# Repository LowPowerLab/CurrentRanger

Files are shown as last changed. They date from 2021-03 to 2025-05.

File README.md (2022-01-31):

# CurrentRanger
Precision auto-ranging current meter (ammeter)

## [Please see the full guide and latest updates posted here.](https://lowpowerlab.com/guide/currentranger/)



## Quick Highlights
Here are some of the features of this instrument which sets it apart:

* Low noise zero-offset with 3-ranges (1mV output per nA/µA/mA)
* Low input burden voltage, high precision & bandwidth analog outputs
* Increased flexibility and usability with several input and output terminal options
* Fast auto-ranging capable
* Use standalone with a small OLED display or with a multimeter/oscilloscope
* Ultra fast range switching between any ranges (even nA to mA) without any glitching/bouncing of a mechanical switch
* Low Pass Filter mode – very useful to capture low noise  signals on oscilloscopes
* Unidirectional mode – most used mode in measuring DC currents ranging from [0, 3.3A]
* Bidirectional mode – split supply biasing allows AC currents measurement ranging from [-1.65A, 1.65A]
* LiPo battery powered – long life and extended measurement range
* Auto-power-off
* Full digital control for power & range switching via touch pads
* OLED display option to read output with usable precision
* Datalogging possible via Bluetooth serial module or USB (use USB isolator, [see guide](https://lowpowerlab.com/guide/currentranger/safety-and-proper-usage/))
* SAMD21 Cortex M0+ powered, change firmware to your needs
* Optional buzzer for audible feedback

* Current ranges output:
  - 0-3300 nA/µA/mA (Unidirectional mode)
  - +/- 0-1650 nA/µA/mA (Bidirectional mode)
  - Burden voltage:
  - 17µV/mA
  - 10µV/µA
  - 10µV/nA
* Output offset voltage¹: typically <10µV, max 50µV
* Maximum input voltage differential (see Safety): 33mV
* Accuracy:
  - +/-0.05% (µA, nA ranges)
  - +/-0.1% (mA range)
* Highest resolution (nA range):
  - 100pA (3.5digit meter)
  - 10pA (4.5 digit meter)
  - 1pA (5.5 digit meter)
* Cascaded ultra low offset/noise amplifiers with 100x output gain
  - Bandwidth: >300KHz (-3dB)

CurrentRanger

Sample no-load mA range comparison to µCurrent GOLD:
mA compare µCurrent

Sample measurement of a [Moteino](https://lowpowerlab.com/guide/moteino/) waking up and transmitting a  RFM69 transceiver packet:

CurrentRanger

## OLED Case
Kindly shared by MariusG, who has also designed the [CurrentViewer](https://github.com/MGX3D/CurrentViewer)


The model can be found [on Thingiverse](https://www.thingiverse.com/thing:4588111/files), and is also shared in this repository in SCAD parameter based format.

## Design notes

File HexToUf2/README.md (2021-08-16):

**Converts a HEX file to UF2 format.**
Check link above here for latest version and more documentation.
https://github.com/microsoft/uf2/blob/master/utils/uf2conv.py

Useful after compiling SAMD21/51 firmware in HEX format, to convert into UF2 format for easy firmware updates without an IDE.
The UF2 output can then be overwritted to/drag-dropped to the bootloader disk drive or sent to customer for in field upgrade of the respective devices.

**Python3 required**

command line usage:

`python3 source.hex -o output.uf2`

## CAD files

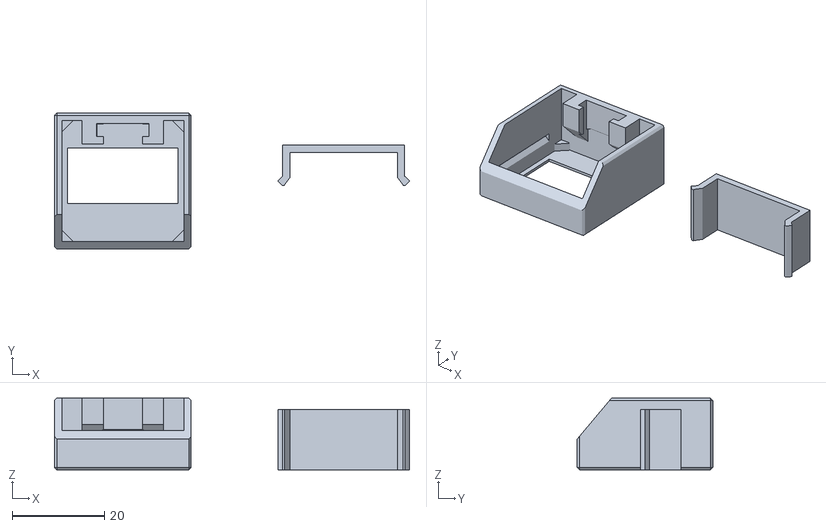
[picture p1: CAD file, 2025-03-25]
CR_OLED.stl
77.1 x 29.5 x 15.6

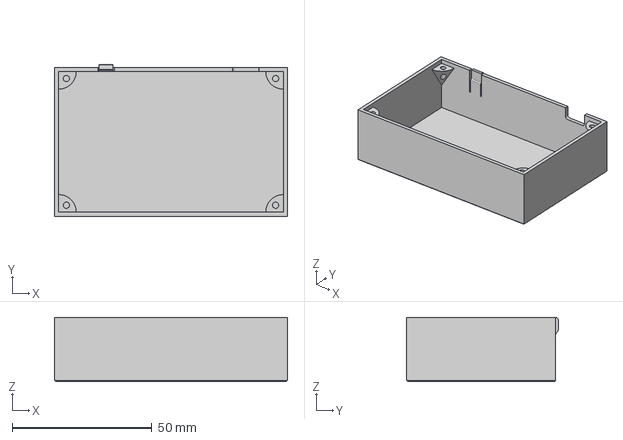
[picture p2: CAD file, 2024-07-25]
CR_R3m6_sideBtn.3mf
83.5 x 54.4 x 23.0 mm

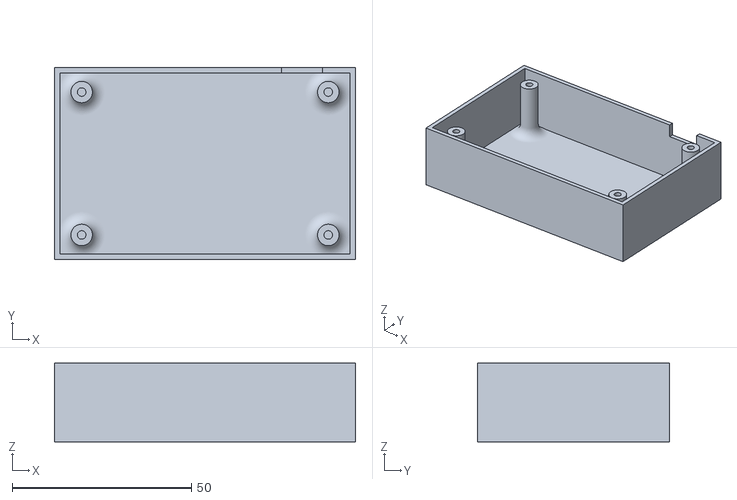
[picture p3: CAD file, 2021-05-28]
CR_R1.stl
84.0 x 53.5 x 22.0

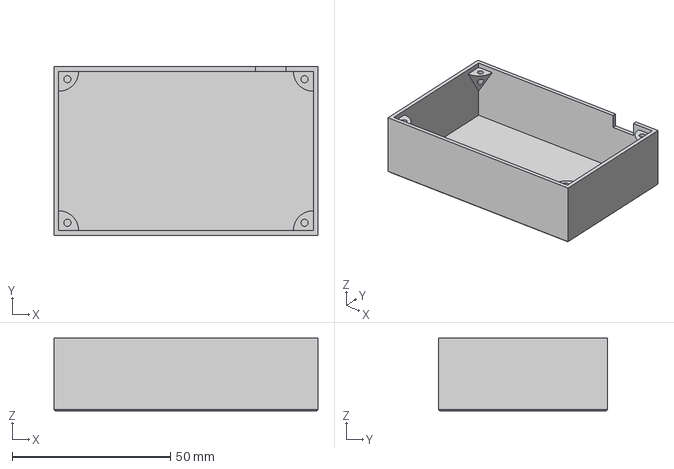
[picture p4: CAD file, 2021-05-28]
CR_R3.step
83.5 x 53.4 x 23.0 mm

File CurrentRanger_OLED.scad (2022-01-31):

// SSD1306 oled module cover
// design by Marius Gheorghescu, September 2020

// offset between the OLED PCB and CurrentRanger PCB
pcb2pcb_offset = 12.60;

// pcb width&height + some clearance
oled_pcb_x = 25.3 + 0.3;
oled_pcb_y = 26.1 + 0.4;

// assuming square pattern
oled_screw_spacing = 21;

// screen dimensions
oled_screen_x = 24;
oled_screen_y = 12;
oled_screen_thickness = 2.4;

// oled offset from center (should be closer to the pins)
oled_screen_y_offset = 1.15;


oled_pcb_thickness = 1.6;

// connector + some clearance
connector_x = 11.3;
connector_y = 2.8;

// ideally multiple of extrusion width to minimize thin walls
wall_thickness = 1.6;
top_wall_thickness = 0.6;

// leave opening to see the logo / access serial 
open_bottom = 1;


// internal and computed values (LCD module + 2-3 layers of print)
epsilon = 0.001;
total_case_height = pcb2pcb_offset + oled_screen_thickness + top_wall_thickness;
retainer_clip_cutout = connector_y + wall_thickness;


module case()
{    
    difference() {

        translate([0, 0, total_case_height/2])
        hull() {
            cube([2*wall_thickness + oled_pcb_x-1, 2*wall_thickness + oled_pcb_y-1, total_case_height], center=true);
            cube([2*wall_thickness + oled_pcb_x, 2*wall_thickness + oled_pcb_y-1, total_case_height-1], center=true);    
            cube([2*wall_thickness + oled_pcb_x-1, 2*wall_thickness + oled_pcb_y, total_case_height-1], center=true);    
        }

        // PCB corner supports (look ma, no screws!)
        translate([0,0, (oled_screen_thickness + oled_pcb_thickness)/2 + top_wall_thickness])
            hull() {
                cube([oled_pcb_x-5, oled_pcb_y, oled_screen_thickness + oled_pcb_thickness], center=true);
                cube([oled_pcb_x, oled_pcb_y-5, oled_screen_thickness + oled_pcb_thickness], center=true);
                translate([0, 0, total_case_height])
                    cube([oled_pcb_x, epsilon, epsilon], center=true);
            }

        // pcb load path
        translate([0,0, total_case_height/2 + oled_screen_thickness])
        {
            difference() {
                
                union() {
                    cube([oled_pcb_x, oled_pcb_y, total_case_height], center=true);                
                }
                
                translate([0, oled_pcb_y/2 - connector_y*0.75, 0])
                    cube([connector_x + 4*wall_thickness, connector_y + + 2*wall_thickness, total_case_height], center=true);                
            }
        }

        // LCD cutout
        translate([0, oled_screen_y_offset, 0])
            cube([oled_screen_x, oled_screen_y, total_case_height], center=true);
        
        // connector    
        taper_amount = 0.08;
        translate([0, oled_pcb_y/2 - connector_y*0.75, total_case_height*3/2 - pcb2pcb_offset])
        {
            hull() {
                translate([0, 0, total_case_height/2])
                    cube([connector_x + taper_amount, connector_y + taper_amount, epsilon], center=true);
                translate([0, 0, -total_case_height/2])
                    cube([connector_x - taper_amount, connector_y - taper_amount, epsilon], center=true);
            }
            

            // connector load clearance
            hull() {
                translate([0, connector_y/8, -total_case_height/3])
                    cube([connector_x, connector_y*1.25, 5], center=true);

                translate([0, -connector_y, 0])
                    cube([epsilon, 4+epsilon, epsilon], center=true);
            }
           
            translate([0,-wall_thickness/2 - epsilon, 0])
                cube([connector_x - connector_y, connector_y+wall_thickness, total_case_height], center=true);
        }
        
    
            
        // retaining clip
        translate([0, -retainer_clip_cutout/2, oled_screen_thickness + oled_pcb_thickness + 1])
        hull() {
            cube([oled_pcb_x + 2, oled_pcb_y - retainer_clip_cutout, epsilon], center=true);
            cube([oled_pcb_x, oled_pcb_y - retainer_clip_cutout, 2], center=true);
        }
            
                
        if (open_bottom) {            
            // opening to see the logo / access the BT/serial connector
            rotate([50,0,0])
            translate([0,0, total_case_height + 100/2])
                cube([100,100,100], center=true);
        }
        
    }

}

module retainer_clip()
{

    // springiness - how much to oversize it so it stays put
    oversize = 0.5;
    
    //clip_height = oled_pcb_y - retainer_clip_cutout - wall_thickness;
    clip_height = oled_pcb_y/2;
    
    difference() {
        
        union() {
            translate([0, total_case_height/4, clip_height/2])
                cube([oled_pcb_x, total_case_height/2, clip_height], center=true);
            
            // wings
            translate([0,0, clip_height/2])
            hull() {
                cube([oled_pcb_x + 2 + oversize, epsilon, clip_height], center=true);
            
                    cube([oled_pcb_x + oversize, 2, clip_height], center=true);
            }
        }

        // make it elastic
        translate([0, total_case_height/4 - wall_thickness, clip_height/2])
            cube([oled_pcb_x - 2*wall_thickness, total_case_height/2, clip_height + epsilon], center=true);
        
        // clearance for the resistors on the PCB, just in case
        hull() {
            translate([0, 0, clip_height/2])
                cube([oled_pcb_x - 2*wall_thickness, wall_thickness, clip_height + epsilon], center=true);
            translate([0, -wall_thickness, clip_height/2])
                cube([oled_pcb_x - 2*wall_thickness + wall_thickness*1.5, wall_thickness, clip_height + epsilon], center=true);
        }

    }
}

case();

translate([2*oled_screen_x, 0, 0])
    retainer_clip();

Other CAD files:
CR_R3.f3d
CR_R3.stl
CR_R3m6_sideBtn.stl

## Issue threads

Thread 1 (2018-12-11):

Details of the switching hardware

PRO2XY, 2018-12-11:
What MOSFETs have been used for the switching hardware?
Is the Rds(on) low enough to be neglected in uA and nA range, or is it required to do some calibration in firmware?

LowPowerLab, 2018-12-11:
Please do not open an issue to ask a question.

Closed 2018-12-11.

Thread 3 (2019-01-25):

Rename vBat to Vin on OLED?

MrSurly, 2019-01-25:
Was concerned that the OLED `vBat` jumped to 4.85V upon applying USB power. Schematic indicates this is actually `Vin`.

I can generate a PR if necessary.

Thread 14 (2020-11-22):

Firmware update documentation not very clear

fguiet, 2020-11-22:
Hi,

I am not reporting a firmware issue here, I just want to mention that the firmware update documentation could be improved.
I found some parts not very obvious to me.

The firmware update documentation can be found here : <https://lowpowerlab.com/guide/currentranger/programming-firmware-updates/>

This part for instance:

> To access the UF2 bootloader, double tap on the RST button

I have got the `Current ranger R3` and I can tell that you will not find any RST button !

After some times, I discovered that there were a tiny label RST on the bottom side of the silkscreen.

Next to that label, one can found 4 plots in the PCB...this were the button should go...

So if you want to go in bootloader mode, you have to use a dupont wire to short 2 plots (in order to reproduce the button action).

Moreover, how can I update my bootloader? It seems that my `current ranger R3` had not been shipped with this new bootloader as it does not appear as a flash drive on Windows 10 Family...

Maybe I have to check this link : <https://github.com/microsoft/uf2-samdx1>

My two cents,
Fred

LowPowerLab, 2020-11-23:
Thanks, I added an INFO paragraph in the [programming page](https://lowpowerlab.com/guide/currentranger/programming-firmware-updates/) to clarify this and the reason why there is no RST button on older units.

Closed 2020-11-23.

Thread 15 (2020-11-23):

Question about the BT check (R3)

mrWheel, 2020-11-23:
@LowPowerLab

Can you please explain this code:
```
#ifdef BT_SERIAL_EN
  //BT check
  Serial.print("Bluetooth AT check @");Serial.print(SERIAL_UART_BAUD);Serial.print("baud...");
  SerialBT.begin(SERIAL_UART_BAUD);
  SerialBT.print("AT"); //assuming HC-06, no line ending required
  uint32_t timer=millis();
  while(millis()-timer<1000) //about 1s to respond
  {
    if (SerialBT.available()==2 && SerialBT.read()=='O' && SerialBT.read()=='K')
    {
      BT_found=true;
      break;
    }
  }

  Serial.print(BT_found?"OK!":"No HC-06 response.\r\nChecking for BT v3.0...");

  if (!BT_found)
  {
    SerialBT.print("\r\n"); //assuming HC-06 version 3.0 that requires line ending
    uint32_t timer=millis();
    while(millis()-timer<50) //about 50ms to respond
    {
      if (SerialBT.available()==4 && SerialBT.read()=='O' && SerialBT.read()=='K' && SerialBT.read()=='\r' && SerialBT.read() == '\n')
      {
        BT_found=true;
        break;
      }
    }

    Serial.println(BT_found?"OK!":"No response.");
  }

  BT_LOGGING_ENABLED = BT_found;
 ```
It is my understanding that the BT device has to be put in "AT-mode" which it normally is not.
So how does the above code block work? I don't think it will ever replay with "OK" being it with or without "\r\n"..

LowPowerLab, 2020-11-23:
The code is pretty self explanatory. It looks for a specific device to respond to an ascii AT command, to confirm its presence or not.

Unfortunately these modules seem to come in all kinds of variants and firmware revisions. They use AT commands to change their settings. If the one you have does not, you will need to find one that does, or modify the firmware to make it work with yours. I would recommend USB logging instead.

I added some details on the [bluetooth/logging page](https://lowpowerlab.com/guide/currentranger/bluetooth-data-logging/) to help clarify some details about this.

Closed 2020-11-23.

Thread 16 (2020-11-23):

BT and OLED ....? (R3)

mrWheel, 2020-11-23:
Hi,

according to this code blok:
```
#ifdef BT_SERIAL_EN
  if (BT_LOGGING_ENABLED) {
    if (OLED_found) {
      u8g2.setFont(u8g2_font_siji_t_6x10); //https://github.com/olikraus/u8g2/wiki/fntgrpsiji
      u8g2.drawGlyph(104, 10, 0xE00B); //BT icon
    }
   .
   .
```
.. it should be possible to have BT logging and the OLED screen at the same time .. but the connector for BT is not exposed when the OLED screen is in place.
Am I missing something?

LowPowerLab, 2020-11-23:
More questions in the forum please.

Closed 2020-11-23.

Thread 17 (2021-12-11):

Serial.begin() missing in CurrentRanger_R3.ino?

anupamvarghese, 2021-12-11:
Can't seem to find Serial.begin(SERIALBAUD) in the R3 sketch. That's perhaps the reason why there is no Serial output and no response to ?+ENTER either?

LowPowerLab, 2021-12-13:
There is no Serial.begin(), it is not needed.
Only UART serial has a begin (`SerialBT.begin()`).

anupamvarghese, 2021-12-13:
My mistake, was trying Termite serial viewer, had to give Flow Control: RTS/CTS instead of NONE to get the serial to work.

Closed 2021-12-13.

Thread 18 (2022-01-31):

Fusion file for CR_OLED?

cmidgley, 2022-01-31:
Any chance you have a Fusion 360 file for `CR_OLED.stl`?  My LCD screens are about 2mm too wide, and adjusting the overall box size makes it sloppy holding on to the socket.  It would be nice to just adjust the outer box without affecting the socket dimensions.

LowPowerLab, 2022-01-31:
Unfortunately I do not have a fusion file. This was designed by the [same person that made the CurrentViewer](https://github.com/MGX3D/CurrentViewer) and he has published his OLED case design [here](https://www.thingiverse.com/thing:4588111/files).

He has now allowed me to publish the SCAD file in this repo.

Closed 2022-01-31.

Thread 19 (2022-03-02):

Question regarding OLED

helmar74, 2022-03-02:
Hi everyone,

sorry for bothering you.
I have a current ranger with oled running.
The OLED shows the following:
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

So my simple Question is:
What does the values in the upper left corner mean?
AUTO is clear for me, as I selected auto range mode.
But what does the values 1/2 and 124 mean?

Thank you in advance

LowPowerLab, 2022-03-02:
This place is for creating issues, the forum is where questions should be places, this question was already answered there.
https://lowpowerlab.com/forum/currentranger/screen-info-on-the-oled/msg29231/#msg29231

helmar74, 2022-03-02:
Hi sorry,
I asked in the forum.
But the shortcuts in the answer don't say me anything:
`The 1/2 means the CR is using half ADC reference where possible (ex in the lower range) for increased resolution of readings. The other number is the ADC reading.`

Closed 2022-03-02.

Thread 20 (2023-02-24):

Can't get an SD card recognized on the SPI pins (R3)

rmptxf, 2023-02-24:
CS pin was set to 3 on the Arduino sketch. We even tried PIN_PA09 and SS too, with no success.
We're looking to record the current measurements into the SD card.
This is the board we're using:
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

LowPowerLab, 2023-02-24:
So how can I help?
Maybe show me the SD board in question and how you connect it to the CR?
Otherwise this is a non CR related problem and issue will be closed, topic is more appropriate in [the forum](https://lowpowerlab.com/forum/currentranger/).

rmptxf, 2023-02-24:
Hi, we've just gotten it up an running now. It was a voltage issue rather than a pin number. The CS is indeed **PIN_PA09**.
Thank you

Closed 2023-02-24.

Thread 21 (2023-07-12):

Log Function

catalinalb, 2023-07-12:
Hello,

Could someone explain or point me to a link where I can find info about how can I log the data on PC?
I do have the Bluetooth device, but over usb would be also ok in this step (I do have an isolator for USB A)

Is there a plotter for windows or linux? Hopefully I don´t need to change the firmware...

Thank you,
Catalin Alb

LowPowerLab, 2023-07-12:
https://lowpowerlab.com/guide/currentranger/bluetooth-data-logging/

Closed 2023-07-12.

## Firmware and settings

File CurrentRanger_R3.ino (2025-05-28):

// CurrentRanger(TM) stock firmware
// https://lowpowerlab.com/CurrentRanger
// CurrentRanger is a *high-side* precision current meter featuring:
//   - fast autoranging
//   - uni/bi-directional modes (ie. DC/AC measurements)
//   - ultra low burden voltage
//   - 1mV per nA/uA/mA measurements with DMM/scope
//   - OLED standalone readings
//   - serial data logging option via 3.3v/RX/TX header or USB (must use isolation, read guide!)
//   - full digital control for power/switching
//   - LiPo powered with auto power-off feature (0.6uA quiescent current)
// *************************************************************************************************************
#ifndef CURRENT_RANGER
  #error CurrentRanger target board required, see guide on how to add it to the IDE: lowpowerlab.com/currentranger
#endif
//***********************************************************************************************************
#include <FlashStorage.h>          //for emulated EEPROM - https://github.com/cmaglie/FlashStorage
#include <Adafruit_FreeTouch.h>    //https://github.com/adafruit/Adafruit_FreeTouch
#include <U8g2lib.h>               //https://github.com/olikraus/u8g2/wiki/u8g2reference fonts:https://github.com/olikraus/u8g2/wiki/fntlistall
//#include <ATSAMD21_ADC.h>

#define FW_VERSION "1.1.6"         //firmware version
// ********************** CHANGE LOG ***********************************************************************
// 1.1.6 - ignore repeated commands for '?'
// 1.1.5 - FEATURE - NEw USB UI command to reset runtimes settings to default values
// 1.1.4 - BUGFIX - USB logging values are half value when CR started without OLED, and until AUTORANGING is toggled
// 1.1.3 - BUGFIX - CR turns off after 21hrs when AUTO-OFF disabled
// 1.1.2 - BUGFIX - BIAS MODE bug fix
//***********************************************************************************************************
#define BIAS_LED       11
#define LPFPIN         4
#define LPFLED         LED_BUILTIN
#define AUTOFF         PIN_AUTO_OFF
//***********************************************************************************************************
#define MA_PIN PIN_PA13  //#define MA  38
#define UA_PIN PIN_PA14  //#define UA  2
#define NA_PIN PIN_PA15  //#define NA  5
#define MA_GPIO_PIN PIN_PB11
#define UA_GPIO_PIN PIN_PA12
#define NA_GPIO_PIN PIN_PB10
#define PINOP(pin, OP) (PORT->Group[(pin) / 32].OP.reg = (1 << ((pin) % 32)))
#define PIN_OFF(THE_PIN) PINOP(THE_PIN, OUTCLR)
#define PIN_ON(THE_PIN) PINOP(THE_PIN, OUTSET)
#define PIN_TGL(THE_PIN) PINOP(THE_PIN, OUTTGL)
//***********************************************************************************************************
#define SENSE_OUTPUT           A3
#define SENSE_GNDISO           A2
#define SENSE_VIN              A5
#define ADC_PRESCALER          ADC_CTRLB_PRESCALER_DIV16
//#define ADC_AVGCTRL            ADC_AVGCTRL_SAMPLENUM_128 | ADC_AVGCTRL_ADJRES(0x4ul)
                               //ADC_AVGCTRL_SAMPLENUM_1 | ADC_AVGCTRL_ADJRES(0x00ul);  // take 1 sample, adjusting result by 0
                               //ADC_AVGCTRL_SAMPLENUM_16 | ADC_AVGCTRL_ADJRES(0x4ul); //take 16 samples adjust by 4
                               //ADC_AVGCTRL_SAMPLENUM_256 | ADC_AVGCTRL_ADJRES(0x4ul); //take 256 samples adjust by 4
                               //ADC_AVGCTRL_SAMPLENUM_512 | ADC_AVGCTRL_ADJRES(0x4ul); //take 512 samples adjust by 4
                               //ADC_AVGCTRL_SAMPLENUM_1024 | ADC_AVGCTRL_ADJRES(0x4ul); //take 1024 samples adjust by 4
#define ADC_SAMPCTRL           0b111 //sample timing [fast 0..0b111 slow]
#define ADCFULLRANGE           4095.0
#define VBAT_REFRESH_INTERVAL  5000 //ms
#define LOBAT_THRESHOLD        3.40 //volts
#define DAC_GND_ISO_OFFSET     10
#define DAC_HALF_SUPPLY_OFFSET 512
#define OUTPUT_CALIB_FACTOR    1.00  //calibrate final VOUT value
#define ADC_OVERLOAD           3900  //assuming GNDISO DAC output is very close to 0, this is max value less ground offset (varies from unit to unit, 3900 is a safe value)
//***********************************************************************************************************
//#define ADC_CALIBRATE_FORCED
#define ADC_CALIBRATE_FORCED_OFFSET 0
#define ADC_CALIBRATE_FORCED_GAIN   2048
#define LDO_DEFAULT                 3.300 //volts, change to actual LDO output (measure GND-3V on OLED header)
//***********************************************************************************************************
#define BUZZER    1   // BUZZER pin
#define NOTE_C5   523
#define NOTE_D5   587
#define NOTE_E5   659
#define NOTE_F5   698
#define NOTE_G5   784
#define NOTE_B5   988
#define NOTE_C6   1047
#define TONE_BEEP 4200
//***********************************************************************************************************
#define MODE_MANUAL                 0
#define MODE_AUTORANGE              1
#define STARTUP_MODE                MODE_MANUAL //or: MODE_AUTORANGE
#define SWITCHDELAY_UP              8 //ms
#define SWITCHDELAY_DOWN            8 //ms
#define RANGE_SWITCH_THRESHOLD_HIGH ADC_OVERLOAD //ADC's 12bit value
#define RANGE_SWITCH_THRESHOLD_LOW  6 //6*0.4xA ~ 2.4xA - range down below this value
//***********************************************************************************************************
#include <Wire.h>                   //i2c scanner: https://playground.arduino.cc/Main/I2cScanner
#define OLED_BAUD                   1600000 //fast i2c clock
#define OLED_ADDRESS                0x3C    //i2c address on most small OLEDs
#define OLED_REFRESH_INTERVAL       180     //ms
U8G2_SSD1306_128X64_NONAME_F_HW_I2C u8g2(U8G2_R0, /* reset=*/ U8X8_PIN_NONE);
//***********************************************************************************************************
#define TOUCH_N        8
#define TOUCH_U        9
#define TOUCH_M        A4
Adafruit_FreeTouch qt[3] = {
  Adafruit_FreeTouch( TOUCH_N, OVERSAMPLE_1, RESISTOR_50K, FREQ_MODE_NONE ),
  Adafruit_FreeTouch( TOUCH_U, OVERSAMPLE_1, RESISTOR_50K, FREQ_MODE_NONE ),
  Adafruit_FreeTouch( TOUCH_M, OVERSAMPLE_1, RESISTOR_50K, FREQ_MODE_NONE ),
};
#define TOUCH_HIGH_THRESHOLD  400 //range is 0..1023
#define TOUCH_SAMPLE_INTERVAL 50 //ms
//***********************************************************************************************************
#define SERIAL_UART_BAUD        230400      //Serial baud for HC-06/bluetooth output
#define BT_SERIAL_EN
//#define LOGGER_FORMAT_EXPONENT  //ex: 123E-3 = 123mA
//#define LOGGER_FORMAT_NANOS     //ex: 123456 = 123456nA = 123.456uA
//#define LOGGER_FORMAT_ADC       //raw ADC output - note: automatic ADC_REF change
#define BT_REFRESH_INTERVAL     200 //ms
//***********************************************************************************************************
#define AUTOOFF_BUZZ_DELAY     500 //ms
#define AUTOOFF_DEFAULT        600 //seconds, turn unit off after 10min of inactivity
#define AUTOOFF_DISABLED       0xFFFFFFFF  // do not turn off
#define AUTOOFF_SMART          0xFFFE  // turn off only if there is no BT or USB data logging
//***********************************************************************************************************
#define LOGGING_FORMAT_EXPONENT 0 //ex: 123E-3 = 123mA
#define LOGGING_FORMAT_NANOS    1 //ex: 1234 = 1.234uA = 0.001234mA
#define LOGGING_FORMAT_MICROS   2 //ex: 1234 = 1.234mA = 1234000nA
#define LOGGING_FORMAT_MILLIS   3 //ex: 1234 = 1.234A = 1234000uA = 1234000000nA
#define LOGGING_FORMAT_ADC      4 //raw output for each range (0..4095)
//***********************************************************************************************************
#define ADC_SAMPLING_SPEED_AVG   0
#define ADC_SAMPLING_SPEED_FAST  1
#define ADC_SAMPLING_SPEED_SLOW  2
//***********************************************************************************************************
int offsetCorrectionValue = 0;
uint16_t gainCorrectionValue = 0;
float ldoValue = 0, ldoOptimized=0;
uint32_t autooff_interval = 0;
uint8_t USB_LOGGING_ENABLED = false;
uint8_t TOUCH_DEBUG_ENABLED = false;
uint8_t GPIO_HEADER_RANGING = false;
uint8_t BT_LOGGING_ENABLED = true;
uint8_t LOGGING_FORMAT = LOGGING_FORMAT_EXPONENT;
uint16_t ADC_SAMPLING_SPEED = ADC_SAMPLING_SPEED_AVG;
uint32_t ADC_AVGCTRL;
uint8_t calibrationPerformed=false;
uint8_t analog_ref_half=false; //keep false to ensure we set the reference correctly
char rangeUnit = 'm';
uint8_t OLED_found=false;
uint8_t autoffWarning=false;
uint8_t autoffBuzz=0;
#ifdef BT_SERIAL_EN
  uint8_t BT_found=false;
#endif
FlashStorage(eeprom_ADCoffset, int);
FlashStorage(eeprom_ADCgain, uint16_t);
FlashStorage(eeprom_LDO, float);
FlashStorage(eeprom_AUTOFF, uint32_t);
FlashStorage(eeprom_LOGGINGFORMAT, uint8_t);
FlashStorage(eeprom_ADCSAMPLINGSPEED, uint8_t);
//***********************************************************************************************************
void setup() {
/*
  //some buzz
  tone(BUZZER, NOTE_C5); delay(100);
  tone(BUZZER, NOTE_E5); delay(100);
  tone(BUZZER, NOTE_G5); delay(100);
  tone(BUZZER, NOTE_C6); delay(200);
  noTone(BUZZER);        delay(50);
  tone(BUZZER, NOTE_G5); delay(100);
  tone(BUZZER, NOTE_C6); delay(400);
  noTone(BUZZER);
*/

  delay(50); //Wire apparently needs this
  Wire.begin();
  Wire.beginTransmission(OLED_ADDRESS);
  byte error = Wire.endTransmission();
  if (error == 0)
  {
    Serial.print("OLED FOUND at 0x"); Serial.println(OLED_ADDRESS);
    u8g2.begin();
    //u8g2.setDisplayRotation(U8G2_R2); //if required (inside/custom mount?)
    u8g2.setBusClock(OLED_BAUD);
    OLED_found = true;
  }
  else Serial.println("NO OLED found...");

  pinMode(A0, OUTPUT); //DAC/GNDISO
  //DAC->CTRLB.bit.EOEN = 0x00; //enable high drive strength - already done in wiring.c

  pinMode(SENSE_OUTPUT, INPUT);
  pinMode(SENSE_GNDISO, INPUT); //GND-ISO
  pinMode(SENSE_VIN, INPUT); //VIN > 1MEG > SENSE_VIN > 2MEG > GND
  pinMode(AUTOFF, INPUT_PULLUP);
  digitalWrite(AUTOFF, HIGH);
  pinMode(BIAS_LED, OUTPUT);
  pinMode(LPFLED, OUTPUT); //STATUS/LPF-LED
  pinMode(LPFPIN, OUTPUT); //LPF control pin
  pinMode(BUZZER, OUTPUT);
  PINOP(MA_PIN, DIRSET);
  PINOP(UA_PIN, DIRSET);
  PINOP(NA_PIN, DIRSET);
  PINOP(MA_GPIO_PIN, DIRSET);
  PINOP(UA_GPIO_PIN, DIRSET);
  PINOP(NA_GPIO_PIN, DIRSET);

  qt[0].begin(); qt[1].begin(); qt[2].begin(); //touch pads
  analogWriteResolution(10);  //DAC resolution
  analogReferenceHalf(false); //call with FALSE then with TRUE to ensure transition and correct POR reference value
  analogReferenceHalf(true);

  //DAC->CTRLA.bit.RUNSTDBY = 0x01;delay(1);
  //DAC->CTRLB.bit.REFSEL=0;//pick internal reference, skip SYNCDAC (done by analogWrite)
  analogWrite(A0, DAC_GND_ISO_OFFSET);  // Initialize Dac to OFFSET

  autooff_interval = eeprom_AUTOFF.read();
  if (autooff_interval==0) {
    autooff_interval = AUTOOFF_DEFAULT;
    eeprom_AUTOFF.write(autooff_interval);
  }

  LOGGING_FORMAT = eeprom_LOGGINGFORMAT.read();

  offsetCorrectionValue = eeprom_ADCoffset.read();
  gainCorrectionValue = eeprom_ADCgain.read();
  ldoValue = eeprom_LDO.read();

  if(ldoValue==0)
    saveLDO(LDO_DEFAULT);
  else ldoOptimizeRefresh();

  ADC_SAMPLING_SPEED = eeprom_ADCSAMPLINGSPEED.read();
  refreshADCSamplingSpeed(); //load correct value into ADC_AVGCTRL

  if (gainCorrectionValue!=0) //check if anything saved in EEPROM (gain changed via SerialUSB +/-)
    analogReadCorrectionForced(offsetCorrectionValue, gainCorrectionValue);
  else {
    analogReadCorrectionForced(ADC_CALIBRATE_FORCED_OFFSET, ADC_CALIBRATE_FORCED_GAIN);
    eeprom_ADCoffset.write(offsetCorrectionValue);
    eeprom_ADCgain.write(gainCorrectionValue);
    //(offset, gain) - gain is 12 bit number (1 bit integer + 11bit fractional, see DS p895)
    //               - offset is 12bit 2s complement format (DS p896)
  }

  if (OLED_found)
  {
    u8g2.clearBuffer();
    u8g2.setFont(u8g2_font_8x13B_tf);
    u8g2.setCursor(15,10); u8g2.print("CurrentRanger");  
    u8g2.setFont(u8g2_font_6x12_tf);
    u8g2.setCursor(0,20); u8g2.print("Offset:");
    u8g2.setCursor(64,20); u8g2.print(offsetCorrectionValue);
    u8g2.setCursor(0,32); u8g2.print("Gain  :");
    u8g2.setCursor(64,32); u8g2.print(gainCorrectionValue);
    u8g2.setCursor(0,44); u8g2.print("LDO   :");
    u8g2.setCursor(64,44); u8g2.print(ldoValue,3);
    u8g2.setCursor(0, 56); u8g2.print("Firmware:");
    u8g2.setCursor(64,56); u8g2.print(FW_VERSION);
    u8g2.sendBuffer();
    delay(2000);
  }

#ifdef BT_SERIAL_EN
  //BT check
  Serial.print("Bluetooth AT check @");Serial.print(SERIAL_UART_BAUD);Serial.print("baud...");
  delay(600);
  SerialBT.begin(SERIAL_UART_BAUD);
  SerialBT.print("AT"); //assuming HC-06, no line ending required
  uint32_t timer=millis();
  while(millis()-timer<1000) //about 1s to respond
  {
    if (SerialBT.available()==2 && SerialBT.read()=='O' && SerialBT.read()=='K')
    {
      BT_found=true;
      break;
    }
  }

  Serial.print(BT_found?"OK!":"No HC-06 response.\r\nChecking for BT v3.0...");

  if (!BT_found)
  {
    SerialBT.print("\r\n"); //assuming HC-06 version 3.0 that requires line ending
    uint32_t timer=millis();
    while(millis()-timer<50) //about 50ms to respond
    {
      if (SerialBT.available()==4 && SerialBT.read()=='O' && SerialBT.read()=='K' && SerialBT.read()=='\r' && SerialBT.read() == '\n')
      {
        BT_found=true;
        break;
      }
    }

    Serial.println(BT_found?"OK!":"No response.");
  }

  BT_LOGGING_ENABLED = BT_found;
#endif

  printSerialMenu();
  WDTset();
  if (STARTUP_MODE == MODE_AUTORANGE) toggleAutoranging();
}

uint32_t oledInterval=0, lpfInterval=0, offsetInterval=0, autorangeInterval=0, btInterval=0,
         autoOffBuzzInterval=0, touchSampleInterval=0, lastKeepAlive=0, vbatInterval = VBAT_REFRESH_INTERVAL;
byte LPF=0, BIAS=0, AUTORANGE=0;
float vbat=0, VOUT=0;
float read1=0,read2=0,readDiff=0;
bool rangeSwitched=false;
#define RANGE_MA rangeUnit=='m'
#define RANGE_UA rangeUnit=='u'
#define RANGE_NA rangeUnit=='n'

void loop() {
  //uint32_t timestamp=micros();
  while (Serial.available()>0) {
    char inByte = Serial.read();

    // tickle the AUTOOFF function so it doesn't shut down when there are commands coming over serial
    lastKeepAlive = millis();

    switch (inByte) {
      case '+':
        eeprom_ADCgain.write(++gainCorrectionValue);
        analogReadCorrection(offsetCorrectionValue,gainCorrectionValue);
        Serial.print("new gainCorrectionValue = ");
        Serial.println(gainCorrectionValue);
        break;
      case '-':
        eeprom_ADCgain.write(--gainCorrectionValue);
        analogReadCorrection(offsetCorrectionValue,gainCorrectionValue);
        Serial.print("new gainCorrectionValue = ");
        Serial.println(gainCorrectionValue);
        break;
      case '*':
        eeprom_ADCoffset.write(++offsetCorrectionValue);
        analogReadCorrection(offsetCorrectionValue,gainCorrectionValue);
        Serial.print("new offsetCorrectionValue = ");
        Serial.println(offsetCorrectionValue);
        break;
      case '/':
        eeprom_ADCoffset.write(--offsetCorrectionValue);
        analogReadCorrection(offsetCorrectionValue,gainCorrectionValue);
        Serial.print("new offsetCorrectionValue = ");
        Serial.println(offsetCorrectionValue);
        break;
      case '<':
        saveLDO(ldoValue-0.001);
        Serial.print("new LDO_Value = ");
        Serial.println(ldoValue, 3);
        break;
      case '>':
        saveLDO(ldoValue+0.001);
        Serial.print("new LDO_Value = ");
        Serial.println(ldoValue, 3);
        break;
      case 'r': //reboot to bootloader
        Serial.print("\nRebooting to bootloader.");
        for (byte i=0;i++<30;) { delay(10); Serial.print('.'); }
        rebootIntoBootloader();
        break;
      case 'u': //toggle USB logging
        USB_LOGGING_ENABLED =! USB_LOGGING_ENABLED;
        Serial.println(USB_LOGGING_ENABLED ? "USB_LOGGING_ENABLED" : "USB_LOGGING_DISABLED");
        break;
      case 'U': //print the USB logging status
        Serial.println(USB_LOGGING_ENABLED ? "USB_LOGGING_ENABLED" : "USB_LOGGING_DISABLED");
        break;
      case 't': //toggle touchpad serial output debug info
        TOUCH_DEBUG_ENABLED =! TOUCH_DEBUG_ENABLED;
        Serial.println(TOUCH_DEBUG_ENABLED ? "TOUCH_DEBUG_ENABLED" : "TOUCH_DEBUG_DISABLED");
        break;
      case 'g': //toggle GPIOs indicating ranging
        GPIO_HEADER_RANGING =! GPIO_HEADER_RANGING;
        if (GPIO_HEADER_RANGING) {
          if (rangeUnit=='m') PIN_ON(MA_GPIO_PIN); else PIN_OFF(MA_GPIO_PIN);
          if (rangeUnit=='u') PIN_ON(UA_GPIO_PIN); else PIN_OFF(UA_GPIO_PIN);
          if (rangeUnit=='n') PIN_ON(NA_GPIO_PIN); else PIN_OFF(NA_GPIO_PIN);
        }
        Serial.println(GPIO_HEADER_RANGING ? "GPIO_HEADER_RANGING_ENABLED" : "GPIO_HEADER_RANGING_DISABLED");
        break;
      case 'b': //toggle BT/serial logging
#ifdef BT_SERIAL_EN
        if (BT_found) {
          BT_LOGGING_ENABLED =! BT_LOGGING_ENABLED;
          Serial.println(BT_LOGGING_ENABLED ? "BT_LOGGING_ENABLED" : "BT_LOGGING_DISABLED");
        } else {
          BT_LOGGING_ENABLED = false;
          Serial.println("BT Module not found: cannot enable logging");
        }
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

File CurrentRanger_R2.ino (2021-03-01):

// *************************************************************************************************************
// CurrentRanger(TM) stock firmware
// https://lowpowerlab.com/CurrentRanger
// CurrentRanger is a high-side precision current meter featuring:
//   - autoranging
//   - uni/bi-directional modes (ie. DC/AC measurements)
//   - ultra low burden voltage
//   - 1mV per nA/uA/mA measurements with DMM/scope
//   - OLED standalone readings
//   - bluetooth data logging option via 3.3v/RX/TX header
//   - full digital control for power/switching
//   - LiPo powered with auto power-off feature (0.6uA quiescent current)
// *************************************************************************************************************
#ifndef CURRENT_RANGER
  #error You need to choose CurrentRanger board as target, see guide for details how to add it to the IDE.
#endif
//***********************************************************************************************************
#include <SAMD_AnalogCorrection.h> //for analogReadCorrection, comes with ArduinoIDE
#include <FlashStorage.h>          //for emulated EEPROM - https://github.com/cmaglie/FlashStorage
#include <Adafruit_FreeTouch.h>    //https://github.com/adafruit/Adafruit_FreeTouch
#include <U8g2lib.h>               //https://github.com/olikraus/u8g2/wiki/u8g2reference fonts:https://github.com/olikraus/u8g2/wiki/fntlistall
//***********************************************************************************************************
#define OFFSET_LED     11
#define LPFPIN         4
#define LPFLED         LED_BUILTIN
#define MA             38
#define UA             2
#define NA             5
#define AUTOFF         PIN_AUTO_OFF
char rangeUnit = 'm';
uint32_t lastRangeChange=0;
//***********************************************************************************************************
#define SENSE_OUTPUT           A3
#define SENSE_GNDISO           A2
#define SENSE_VIN              A5
#define ADCREADINGS            1   //do averaging in hardware rather than software
#define ADC_PRESCALER          ADC_CTRLB_PRESCALER_DIV16
#define ADC_AVGCTRL            ADC_AVGCTRL_SAMPLENUM_256 | ADC_AVGCTRL_ADJRES(0x4ul)
#define ADCFULLRANGE           4095.0
#define VBATREADLOOPS          100  //read vbat every this many OLED_REFRESH_INTERVAL loops
#define LOBAT_THRESHOLD        3.40 //volts
#define DAC_GND_ISO_OFFSET     10
#define DAC_HALF_SUPPLY_OFFSET 512
#define OUTPUT_CALIB_FACTOR    1.00  //calibrate final VOUT value
#define ADC_OVERLOAD           3900  //assuming GNDISO DAC output is very close to 0, this is max value less ground offset (varies from unit to unit, 3900 is a safe value)
//***********************************************************************************************************
#define ADC_CALIBRATE_EN
#define ADC_CALIBRATE_FORCED          //uncomment to set manual offset/gain values below
#define ADC_CALIBRATE_FORCED_OFFSET 0
#define ADC_CALIBRATE_FORCED_GAIN   2048
#define LDO_OUTPUT                  3.300 //volts, change to actual LDO output (measure GND-3V on OLED header)
#define ANALOG_REFERENCE            AR_DEFAULT //AR_EXTERNAL
//***********************************************************************************************************
#define BUZZER     1           // BUZZER pin
#define NOTE_C5  523
#define NOTE_D5  587
#define NOTE_E5  659
#define NOTE_F5  698
#define NOTE_G5  784
#define NOTE_B5  988
#define NOTE_C6  1047
#define TONE_BEEP 4200
//***********************************************************************************************************
#define MODE_MANUAL 0
#define MODE_AUTORANGE 1
#define STARTUP_MODE        MODE_MANUAL //MODE_AUTORANGE
#define SWITCHDELAY_UP      8 //ms
#define SWITCHDELAY_DOWN    8 //ms
#define RANGE_SWITCH_THRESHOLD_HIGH ADC_OVERLOAD //ADC's 12bit value
#define RANGE_SWITCH_THRESHOLD_LOW  0
//***********************************************************************************************************
#include <Wire.h>
//i2c scanner: https://playground.arduino.cc/Main/I2cScanner
#define OLED_ADDRESS  0x3C //i2c address on most small OLEDs
#define OLED_REFRESH_INTERVAL 200 //ms
U8G2_SSD1306_128X64_NONAME_F_HW_I2C u8g2(U8G2_R0, /* reset=*/ U8X8_PIN_NONE);
byte OLED_found=false;
//***********************************************************************************************************
#define TOUCH_N        8
#define TOUCH_U        9
#define TOUCH_M        A4
Adafruit_FreeTouch qt[3] = {
  Adafruit_FreeTouch( TOUCH_N, OVERSAMPLE_8, RESISTOR_20K, FREQ_MODE_HOP ),
  Adafruit_FreeTouch( TOUCH_U, OVERSAMPLE_8, RESISTOR_20K, FREQ_MODE_HOP ),
  Adafruit_FreeTouch( TOUCH_M, OVERSAMPLE_8, RESISTOR_20K, FREQ_MODE_HOP ),
};
#define TOUCH_HIGH_THRESHOLD  600   //range is 0..1023
#define MA_PRESSED      qt[2].measure()>TOUCH_HIGH_THRESHOLD
#define MA_NOT_PRESSED  !(MA_PRESSED)
#define UA_PRESSED      qt[1].measure()>TOUCH_HIGH_THRESHOLD
#define UA_NOT_PRESSED  !(UA_PRESSED)
#define NA_PRESSED      qt[0].measure()>TOUCH_HIGH_THRESHOLD
#define NA_NOT_PRESSED  !(NA_PRESSED)
//***********************************************************************************************************
#define SERIAL_UART_BAUD    230400      //Serial baud for HC-06/bluetooth output
#define BT_EN
#define LOGGER_FORMAT_EXPONENT  //ex: 123E-3 = 123mA
//#define LOGGER_FORMAT_NANOS     //ex: 123456 = 123456nA = 123.456uA
//#define LOGGER_FORMAT_ADC       //raw ADC output
#define BT_REFRESH_INTERVAL 200 //ms
#define AUTOFF_DEFAULT  600     //seconds, turn unit off after 10min of inactivity
//***********************************************************************************************************
int offsetCorrectionValue = 0;
uint16_t gainCorrectionValue = 0;
float ldoValue = 0;
uint16_t AUTOFF_INTERVAL = 0;
uint8_t USB_LOGGING_ENABLED = false;
uint8_t BT_LOGGING_ENABLED = true;
byte calibrationPerformed=false;
#ifdef BT_EN
  byte BT_found=false;
#endif
FlashStorage(eeprom_ADCoffset, int);
FlashStorage(eeprom_ADCgain, uint16_t);
FlashStorage(eeprom_LDO, float);
FlashStorage(eeprom_AUTOFF, uint16_t);
//***********************************************************************************************************
#define AUTOFFBUZZDELAY 500
byte AUTOOFFBUZZ=0;
uint32_t autoOffBuzzInterval=0;
byte autoffWarning=false;
//***********************************************************************************************************
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

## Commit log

2018-10-29 i2c 1mhz clock
    requires latest u8g2 update
2018-12-10 minor updates
    OLED calibration values shown only when MA_PRESSED at startup
2019-01-15 Fix calibration, autoranging "bouncing"
    [CurrentRanger_R1.ino]
2019-05-09 Added support for HC-06 firmware version 3.0-20170609
    - New HC-06 firmware version 3.0-20170609 requires a line feed (CR/LF) included in AT commands. It also sends the line feed after each response. This version fixes the BlueTooth module recognition with the new HC-06 firmware version.
    [CurrentRanger_R1.ino]
2019-11-29 range up to mA to prevent brown outs
    [CurrentRanger_R1.ino]
2020-06-16 Update CurrentRanger R3.UF2
2020-06-18 fast range/GPIO switching
    https://lowpowerlab.com/forum/moteino-m0/best-way-to-speed-up-rfm69hcw-data-throughput-on-moteino-m0/msg27639/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
2020-09-06 Fixed missing beep on autorange
    [CurrentRanger_R3.ino]
2020-09-06 Added battery icon to use 10x less pixels on the OLED
2020-09-07 Replace vBat with icons, show BT icon if BT_found
    [CurrentRanger_R3.ino]
2021-05-28 Add R3 CAD models (STEP, F3D, STL)
    [CR_R3.f3d, CR_R3.step, CR_R3.stl]
2021-05-28 Add R1 CAD (STL)
    [CR_R1.stl]
2021-07-07 v1.1.1
    - fix BIAS bug
    - add ranging control over USB serial
    - flip /* with +- for gain/offset
    [CurrentRanger_R3.ino]
2021-08-04 v1.1.2: BIAS MODE bug fix
    Obsoletes v1.1.1
    [CurrentRanger_R3.ino]
2022-01-31 Create CurrentRanger_OLED.scad
    Closes #18
    [CurrentRanger_OLED.scad]
2022-04-22 Firmware v1.1.3 release
    Fix AUTOFF bug timing out after ~20hours
    [CurrentRanger_R3.ino]
2024-07-25 Add R3 m6 case
    [CR_R3m6_sideBtn.3mf, CR_R3m6_sideBtn.stl]
2024-09-03 v1.1.4: Bugfix - USB values half on POR with no OLED
    [CurrentRanger_R3.ino]
2025-02-06 v1.1.5 - add '!' command to reset all settings
    [CurrentRanger_R3.ino]
2025-05-23 Revert "Added command U to show the status of the USB logging."
    This reverts commit 98caabde1765a6542ae5cd295d2193aaeafc2c45.
    [CurrentRanger_R3.ino]
2025-05-23 Added command S to show the status of the ADC Sampling speed.
2025-05-23 On my keyboard '?' and '/' are the same key. I changed the calibration offset a few times looking for a menu. This also puts the calibration + and - right next to each other.
